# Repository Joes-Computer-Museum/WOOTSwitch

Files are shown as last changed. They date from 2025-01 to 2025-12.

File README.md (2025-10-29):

WOOTSwitch
==========

WOOTSwitch is a hardware fork of hootswitch by saybur.
WOOTSwitch is a prototype [ADB](https://en.wikipedia.org/wiki/Apple_Desktop_Bus)
multiplexer that allows peripherals (inluding keyboards and mice) to be shared
across up to four retro computers.

This project has two parts: an hardware design and the firmware,
located in their respective folders in this repo.

The hardware design uses Raspberry Pi Pico design files found here:
https://github.com/HeadBoffin/RP_Silicon_KiCad

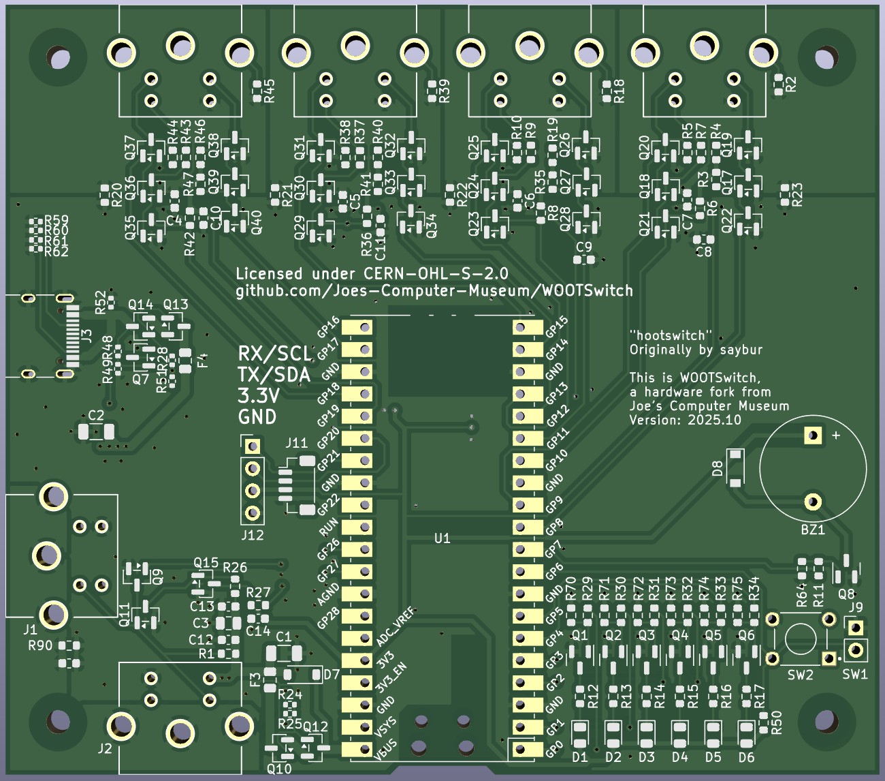
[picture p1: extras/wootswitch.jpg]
WOOTSwitch


Status
------

Basic ADB keyboards and mice are supported. Switching between computers works
via the button on the front or <kbd>Control</kbd> / <kbd>Option</kbd> /
<kbd>⌘</kbd> / <kbd>Shift</kbd> in sequence, followed by <kbd>1</kbd> -
<kbd>4</kbd> to choose a port.

The firmware is still under active development and many bugs remain. Known
issues include:

- Mouse input can be a bit "floaty" especially during extreme movements.
- No other ADB devices besides keyboards/mice are supported yet.
- No features based on the Pico W wireless chip have not been implemented.

This section will continue to be updated as progress is (hopefully) made.

Building
--------

You will need the Pico SDK and associated tooling. There is a setup script
[here](https://raw.githubusercontent.com/raspberrypi/pico-setup/master/pico_setup.sh)
that assumes you're using a Raspberry Pi as your development environment if you
want to try that; I personally use Debian _bookworm_ on a regular x86 system
instead, set up as follows.

Dependencies and associated tools:

```
sudo apt install git cmake gcc-arm-none-eabi gcc gdb-multiarch automake \
    autoconf build-essential texinfo libtool libftdi-dev libusb-1.0-0-dev \
    openocd
```

Clone the [Pico SDK](https://github.com/raspberrypi/pico-sdk). Execute
`git submodule update --init` in that project to get sub-libraries added. Set
`PICO_SDK_PATH` to point at where the SDK lives via `~/.bashrc` or equivalent;
something like `export PICO_SDK_PATH=/home/saybur/src/pico-sdk` would be
suitable after being adjusted for your environment.

Also clone or download [FreeRTOS](https://github.com/FreeRTOS). The LTS release
is likely fine. Set `FREERTOS_KERNEL_PATH` to the folder where
`FreeRTOS-Kernel` is located via the above method.

Once you have everything set up, build as follows from the root of the repo.

```
mkdir -p build
cd build
cmake ../firmware
make
```

Among other files, this will produce `hootswitch.uf2`. Make sure your power
selection is correct, then hold down the BOOTSEL button while you plug in
to your computer via USB. Copy the `.uf2` onto the new mass storage device.
Reboot.

Licenses
--------

Except where otherwise noted, all software is available under the GNU GPL v3.
The example hardware is available under the CERN Open Hardware Licence
strongly-reciprocal variant, version 2. Refer to the licenses for specific
terms.

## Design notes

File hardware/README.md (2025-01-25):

Hootswitch Hardware
===================

_IMPORTANT NOTE_: the DC power jack does not work on any board revision due to
a design error. If you make PCBs based on this design only USB power will
function. You can work around this problem by bodging a wire from the negative
terminal of the DC jack to a nearby ground connection but that isn't great for
such an important connection.

This folder has the hardware design being used to develop the firmware. Known
issues with it include:

- Some features are untested, including alternate power modes.
- C1 in the BOM is wrong. Since I am not using the power input at the moment I
  left it unpopulated.
- There is no keepout for the wireless chip, which may negatively impact
  reception.
- Annular rings on the mini-DIN connectors are on the small side.
- Green LEDs are too bright. Adjusted in 2024a with PWM. Future revision needs
  stronger resistors.
- Mounting holes are too small for the standard screws. These are also a tad
  too close to the connectors.
- A connection should be made between host power-on and a free GPIO. This can
  be worked around in software with keyboards.
- It might have been wiser to put bus input pins to GPIOs with PWM B inputs.
  This will probably not be changed, PIO handles everything fine.

Anticipate that a future revision will be made with corrections.
[CHANGES.txt](CHANGES.txt) will have any applicable history.

This project is made available under the CERN Open Hardware Licence
strongly-reciprocal variant version 2, available at [LICENSE](LICENSE).

This is distributed WITHOUT ANY EXPRESS OR IMPLIED WARRANTY, INCLUDING OF
MERCHANTABILITY, SATISFACTORY QUALITY AND FITNESS FOR A PARTICULAR PURPOSE.
Please see the CERN-OHL-S v2 for applicable conditions.

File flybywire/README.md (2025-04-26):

Fly-By-Wire
===========

The web portion of the serial link control system used by Hootswitch. Visit
<https://saybur.github.io/hootswitch/flybywire/> to access.

To set configuration information, visit
<https://saybur.github.io/hootswitch/flybywire/config.html> and refer to the
wiki for additional information.

External Dependencies
---------------------

- `simple_keyboard.js` and `simple-keyboard.css` are from the
[Simple Keyboard](https://github.com/hodgef/simple-keyboard) project.
- `keyboard-capture.js` and `keyboard-capture.css` are from the
[IP-KVM-InterFace](https://github.com/SterlingButters/ip-kvm-interface)
project. Refer to those files for license information.
- `crc32.js` is in the public domain and is from
[https://simplycalc.com/crc32-source.php](https://simplycalc.com/)

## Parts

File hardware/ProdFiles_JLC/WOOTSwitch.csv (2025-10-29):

Designation | Designator | Footprint | LCSC Part Number
1M | R52,R51 | R_0402_1005Metric | C26083
10k | R49,R28,R25,R62,R61,R60,R59 | R_0402_1005Metric | C25744
100 | R48,R24 | R_0402_1005Metric | C25076
AO3401A | Q14,Q13,Q12,Q10 | SOT-23 | C15127
47uF | C1,C2 | C_1206_3216Metric | C96123
500mA | F4,F3 | Fuse_0805_2012Metric | C883111
B5819W | D7,D8 | D_SOD-123 | C8598
AO3400A | Q7 | SOT-23 | C20917
USB_C_Receptacle | J3 | USB_C_Receptacle_HRO_TYPE-C-31-M-12 | C165948
4.7k | R5,R9,R44,R10,R43,R37,R7,R38,R50 | R_0603_1608Metric | C23162
33 | R39,R90,R2,R18,R45 | R_0603_1608Metric | C23140
10k | R20,R46,R21,R35,R41,R47,R40,R4,R3,R22,R19,R26,R23,R72,R73,R71,R64,R75,R70,R74 | R_0603_1608Metric | C25804
2N7002 | Q22,Q28,Q20,Q23,Q27,Q29,Q36,Q9,Q15,Q31,Q21,Q35,Q19,Q34,Q33,Q30,Q38,Q24,Q11,Q39,Q40,Q32,Q26,Q18,Q25,Q17,Q37 | SOT-23 | C8545
RLED | D1 | LED_0805_2012Metric | C84256
LED | D3,D5,D4,D6 | LED_0805_2012Metric | C2297
YLED | D2 | LED_0805_2012Metric | C2296
100nF | C13,C8,C12,C14,C9,C11,C10 | C_0603_1608Metric | C14663
10n | C5,C4,C7,C6 | C_0603_1608Metric | C57112
1k | R6,R42,R27,R8,R36,R12,R15,R13,R11,R16,R14,R17 | R_0603_1608Metric | C21190
MMBT3904 | Q8,Q3,Q1,Q4,Q2,Q6,Q5 | SOT-23 | C20526
2K2 | R31,R29,R32,R30,R33,R34 | R_0603_1608Metric | C4190
1825910-6 | SW2 | SW_1825910-6-4 | C428628
470 | R1 | R_0603_1608Metric | C23179
10uF | C3 | C_0805_2012Metric | C15850

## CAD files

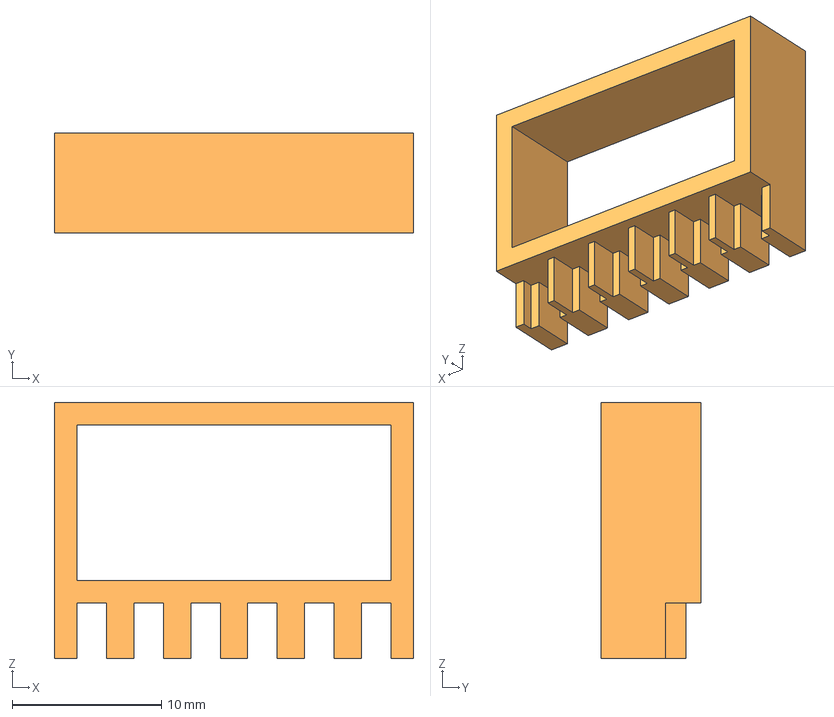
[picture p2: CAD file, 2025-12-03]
hardware/enclosure/WOOTswitch Enclosure - Light Pipe Comb.step
24.0 x 6.68 x 17.1 mm

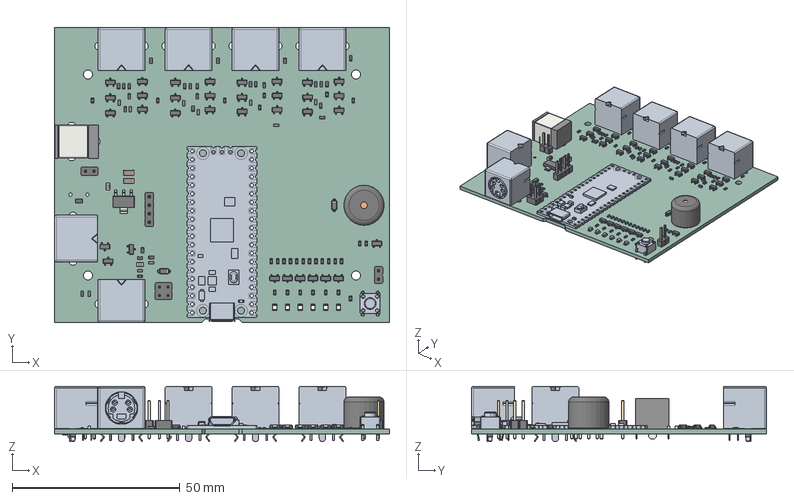
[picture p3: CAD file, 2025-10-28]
hardware/WOOTSwitch.step
100.0 x 88.0 x 16.6 mm
R_0603_1608Metric x 53
SOT-23 x 34
LED_0805_2012Metric x 6
C_0603_1608Metric x 11
L_0603_1608Metric
Fuse_0805_2012Metric
c-5749181-1-a-3d x 6
PinHeader_1x02_P2.54mm_Vertical x 2
c-1825910-6-c-3d
BarrelJack_CUI_PJ-063AH_Horizontal
WOOTSwitch 1.57.1
SOT-223
Buzzer_12x9.5RM7.6
C_1206_3216Metric x 2
PinHeader_1x04_P2.54mm_Vertical
D_SOD-123 x 2
C_0805_2012Metric x 2
PinHeader_2x02_P2.54mm_Vertical
WOOTSwitch_PCB

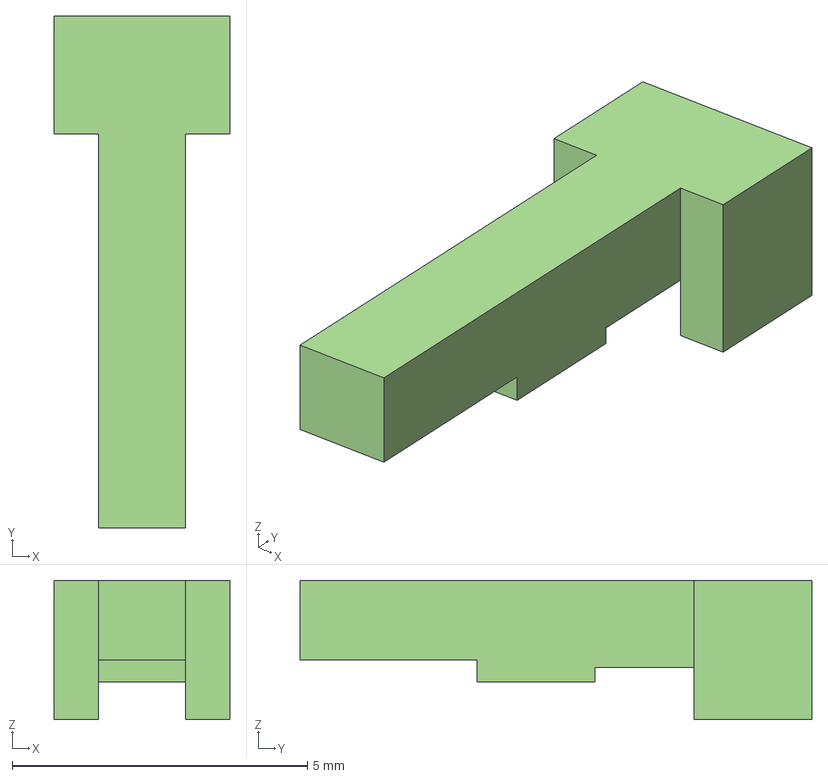
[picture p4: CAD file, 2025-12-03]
hardware/enclosure/WOOTswitch Enclosure - Light Pipe.step
2.97 x 8.68 x 2.36 mm

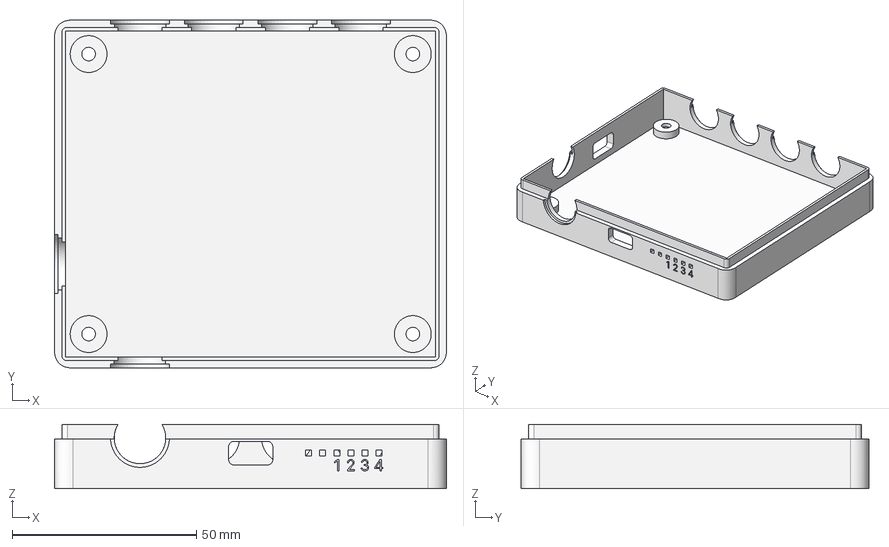
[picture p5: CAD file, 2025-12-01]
hardware/enclosure/WOOTswitch Enclosure - Bottom.step
106.4 x 94.4 x 17.4 mm

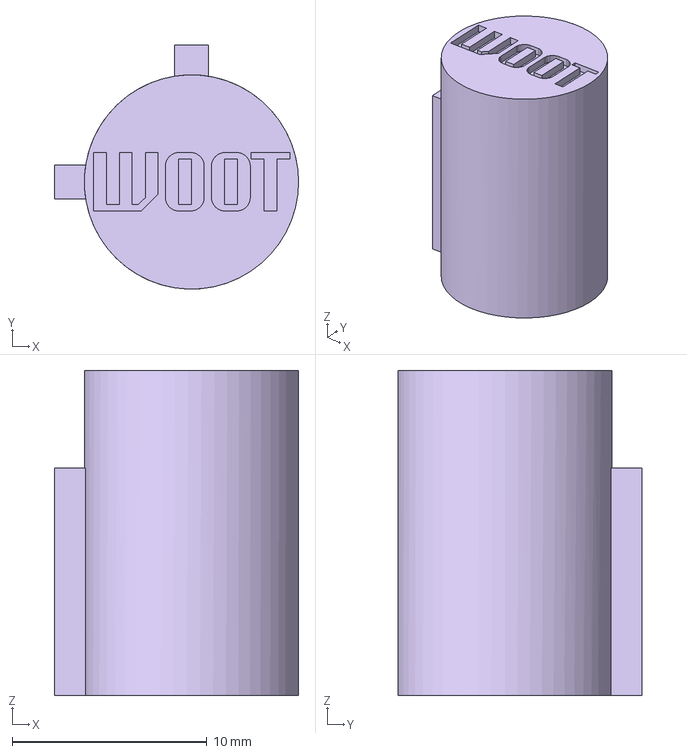
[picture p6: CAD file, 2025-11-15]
hardware/enclosure/WOOTswitch Enclosure - Button.step
12.5 x 12.5 x 16.7 mm

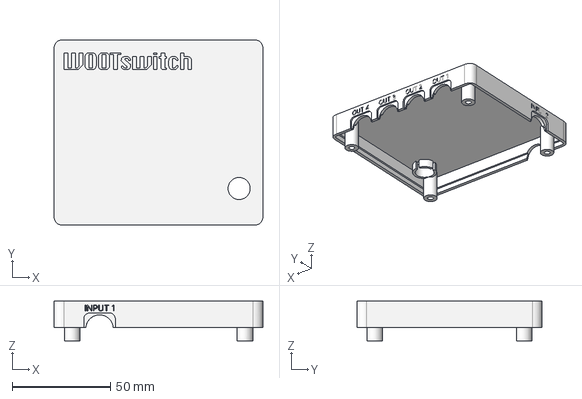
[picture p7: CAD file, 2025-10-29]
hardware/enclosure/WOOTswitch Enclosure - Top.step
106.4 x 94.4 x 20.3 mm

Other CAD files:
hardware/enclosure/WOOTswitch Enclosure - Bottom.stl
hardware/enclosure/WOOTswitch Enclosure - Button.stl
hardware/enclosure/WOOTswitch Enclosure - Light Pipe Comb.stl
hardware/enclosure/WOOTswitch Enclosure - Light Pipe.stl
hardware/enclosure/WOOTswitch Enclosure - Top.stl

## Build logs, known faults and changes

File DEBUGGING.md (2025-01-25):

Debugging
=========

These are notes for a potential way to debug the device during development.
This is how I (@saybur) personally like working on it in a Linux desktop
environment.

Logging
-------

Hootswitch will log some aspects of device detection, host startup, and similar
lifecycle events to the USB CDC device. Connect at 115200 baud, 8-N-1.

Hardware
--------

To capture ADB signals I use an inexpensive logic analyzer compatible with the
`fx2lafw` firmware from the
[sigrok](https://sigrok.org/wiki/Main_Page) project. To sample the device-side
the passthrough ADB connector works great. For one of the hosts you can either
use the second ADB port on a computer that has one (IIci and the like) or a
hacked-together ADB splitter of some kind.

[PulseView](https://sigrok.org/wiki/PulseView) works for reviewing captures. It
works even better with an ADB decoder like
[decoder-adb](https://github.com/tmk/decoder-adb). On my system that had to be
installed in ` ~/.local/share/libsigrokdecode/decoders` in an `adb` subfolder.

Software
--------

You will want to invoke `cmake` with `-DCMAKE_BUILD_TYPE=Debug`.

[The official debugger](https://www.raspberrypi.com/documentation/microcontrollers/debug-probe.html)
is dirt cheap and works reasonably well if you plan to develop on the firmware.
It can be used as follows to upload without needing to fuss with the BOOTSEL
button. Be in the `dialout` group to avoid needing `sudo` all over the place.
OpenOCD can be started as follows.

```
openocd -c "set USE_CORE 0" -f interface/cmsis-dap.cfg -f target/rp2040.cfg \
    -c "adapter speed 5000" -c "rp2040.core0 configure -rtos FreeRTOS"
```

See <https://github.com/raspberrypi/pico-sdk/issues/1622> for a discussion
about `USE_CORE 0` above. The above is fine for now with the current state of
development, which runs only on a single core anyway.

In another terminal, run `gdb-multiarch hootswitch.elf`. Connect to the device
with `target remote localhost:3333` (or automate this step via `~/.gdbinit`).
See [the documentation](https://openocd.org/doc/html/General-Commands.html) for
specifics; the following commands are likely useful (with the caveat that I am
_most definitely_ not an authority on `gdb`):

* `load` will update programming with the current ELF.
* `monitor reset init` will restart and halt for instructions.
* `print X` prints information about something, including variables.
* `br X` adds a breakpoint at X, `del` removes one or more.
* `continue` will proceed, stopping at breakpoints; Ctrl-C halts.
* `finish` completes a function.
* `bt` prints a backtrace, `bt f` prints a backtrace with symbols.
* `up` and `down` moves around the frames of a call.
* `i r` prints registers.
* `p X` prints variable X.
* `p/x *0x0` prints in hex from the address, useful for peripheral registers.
* `i threads` prints information relevant to FreeRTOS thread execution.

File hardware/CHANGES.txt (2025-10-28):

DESIGN CHANGES

Refer to section 3.3.b of the license for information that must be included in
this document.

- 23 July 2024, rev 2024a: first design
- September 2025, rev 2025.09: Changed to mosfets for isolation
- October 2025, rev 2025.10: Changed pushbutton, rebranded as WOOTSwitch

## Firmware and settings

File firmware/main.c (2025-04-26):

/*
 * Copyright (C) 2024 saybur
 *
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
 * You should have received a copy of the GNU General Public License
 * along with this program.  If not, see <https://www.gnu.org/licenses/>.
 */

#include <stdio.h>
#include "pico/stdlib.h"
#include "pico/cyw43_arch.h"
#include "hardware/gpio.h"

#include "FreeRTOS.h"
#include "task.h"

#include "button.h"
#include "buzzer.h"
#include "computer.h"
#include "config.h"
#include "control.h"
#include "debug.h"
#include "driver.h"
#include "host.h"
#include "hardware.h"
#include "led.h"
#include "usb.h"

#define PROGRAM_NAME       "hootswitch-v20250426"

#define DEFAULT_STACK      configMINIMAL_STACK_SIZE
#define DEFAULT_PRIORITY   (tskIDLE_PRIORITY + 1U)
#define DISPATCH_PRIORITY  (tskIDLE_PRIORITY + 2U)

static void init_hardware(void)
{
	led_init();

	buzzer_init();
	host_init();
	computer_init();

	// setup input switch
	gpio_init(SWITCH_PIN);
	gpio_pull_up(SWITCH_PIN);
}

static void init_config(void)
{
	config_setup();

	// read core configuration information, and on failure leave at defaults
	uint8_t core;
	if (config_read(CONFIG_OFFSET_BASE, &core, 1)) {
		return;
	}

	if (! (core & 1)) {
		buzzer_enable(false);
	}
}

static void init_task(__unused void *parameters)
{
	// wait for USB enumeration, and for ADB devices to power up themselves up
	busy_wait_ms(1600);

	// handle alternate startup conditions
	switch (control_check_reset()) {
		case RESET_TYPE_DEBUG:
			// wait for a USB UART to connect
			bool led = false;
			while (! stdio_usb_connected()) {
				vTaskDelay(100);
				cyw43_arch_gpio_put(CYW43_WL_GPIO_LED_PIN, led);
				led = !led;
			}
			cyw43_arch_gpio_put(CYW43_WL_GPIO_LED_PIN, 1);
			break;
	}

	dbg(PROGRAM_NAME);
	init_config();
	led_activity(true);
	handler_init();

	host_err herr;
	if (herr = host_reset_bus()) {
		dbg_err("host bus reset err %d", herr);
		led_error(true);
	}
	busy_wait_ms(1);
	if (herr = host_reset_devices()) {
		dbg_err("host device reset err %d", herr);
		led_error(true);
	} else {
		dbg("host reset ok!");
	}

	driver_init();
	computer_start();
	computer_switch(1, true);
	control_start();

	xTaskCreate(computer_task, "computer", DEFAULT_STACK,
			NULL, DISPATCH_PRIORITY, NULL);
	xTaskCreate(host_task, "host", DEFAULT_STACK,
			NULL, DISPATCH_PRIORITY, NULL);
	xTaskCreate(button_task, "button", DEFAULT_STACK,
			NULL, DEFAULT_PRIORITY, NULL);
	xTaskCreate(control_task, "control", configMINIMAL_STACK_SIZE,
			NULL, tskIDLE_PRIORITY, NULL);

	vTaskDelete(NULL);
}

int main(void)
{
	usb_dev_init();
	stdio_init_all();
	if (cyw43_arch_init()) {
		panic("unable to init cyw43, is this a Pico W?");
	}
	cyw43_arch_gpio_put(CYW43_WL_GPIO_LED_PIN, 1);

	init_hardware();

	xTaskCreate(init_task, "init", DEFAULT_STACK,
			NULL, DEFAULT_PRIORITY, NULL);
	xTaskCreate(usb_dev_task, "usb_dev", DEFAULT_STACK * 3,
			NULL, configMAX_PRIORITIES - 1, NULL);

	while (true) {
		vTaskStartScheduler();
	}
}

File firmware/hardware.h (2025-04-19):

/*
 * Copyright (C) 2024 saybur
 *
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
 * You should have received a copy of the GNU General Public License
 * along with this program.  If not, see <https://www.gnu.org/licenses/>.
 */

#ifndef __HARDWARE_H__
#define __HARDWARE_H__

/*
 * ----------------------------------------------------------------------------
 *     PIN DEFINITIONS
 *   Change these to match your hardware.
 * ----------------------------------------------------------------------------
 *
 * The RP2040 has fewer "gotchas" than other MCUs but there still are some
 * limitations to be aware of if you're trying a new board spin:
 *
 * - LEDs should not be on PWMs shared with other periphals that use the PWM
 *   system, such as the buzzer, or you will need to adjust the LED driving
 *   code.
 * - Generally try to have the _DO lines on PWM_CHB (odd GPIOs), they are the
 *   only ones with duty cycle / frequency measuring. This is not currently
 *   implemented, PIO handles all that stuff, but it might be useful in the
 *   future.
 */

#define LED_ERR_PIN         0
#define LED_ACT_PIN         1
#define LED_C1_PIN          2
#define LED_C2_PIN          3
#define LED_C3_PIN          4
#define LED_C4_PIN          5
#define SWITCH_PIN          6
#define BUZZER_PIN          7
#define A_DO_PIN            26
#define A_DI_PIN            27
#define C1_DO_PIN           18
#define C1_DI_PIN           19
#define C1_PSW_PIN          17
#define C2_DO_PIN           15
#define C2_DI_PIN           16
#define C2_PSW_PIN          14
#define C3_DO_PIN           12
#define C3_DI_PIN           13
#define C3_PSW_PIN          11
#define C4_DO_PIN           9
#define C4_DI_PIN           10
#define C4_PSW_PIN          8

/*
 * ----------------------------------------------------------------------------
 *     RESOURCE DEFINITIONS / ALIASES
 *   Use care changing anything past this line!
 * ----------------------------------------------------------------------------
 */

// "computer" refers to the emulated device ports on the back
#define COMPUTER_PIO        pio0
#define COMPUTER_PIO_IRQ0   PIO0_IRQ_0
#define COMPUTER_COUNT      4

// device DMA units, used to handle initial signal detection and Listen data
#define COMPUTER_DMA_IRQ    DMA_IRQ_1
#define COMPUTER_DMA_IDX    1
#define COMPUTER_DMA_INTS   dma_hw->ints1
#define COMPUTER_0_DMA      6
#define COMPUTER_1_DMA      7
#define COMPUTER_2_DMA      8
#define COMPUTER_3_DMA      9

// additional DMA channel used for handling configuration data
#define CONFIG_DMA_CHAN     5

// "host" refers to the connection with the native peripherals on the front
#define HOST_PIO            pio1
#define HOST_PIO_IRQ0       PIO1_IRQ_0

#define BUZZER_TIMER        2
#define BUZZER_TIMER_IRQ    TIMER_IRQ_2
#define COMPUTER_TIMER      1
#define COMPUTER_TIMER_IRQ  TIMER_IRQ_1
#define HOST_TIMER          0
#define HOST_TIMER_IRQ      TIMER_IRQ_0

#define A_DO_PIN_bm         (1U << A_DO_PIN)
#define C1_DO_PIN_bm        (1U << C1_DO_PIN)
#define C2_DO_PIN_bm        (1U << C2_DO_PIN)
#define C3_DO_PIN_bm        (1U << C3_DO_PIN)
#define C4_DO_PIN_bm        (1U << C4_DO_PIN)

#define A_DO_PIN_bm         (1U << A_DO_PIN)
#define C1_DO_PIN_bm        (1U << C1_DO_PIN)
#define C2_DO_PIN_bm        (1U << C2_DO_PIN)
#define C3_DO_PIN_bm        (1U << C3_DO_PIN)
#define C4_DO_PIN_bm        (1U << C4_DO_PIN)

#endif /* __HARDWARE_H__ */

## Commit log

2025-01-20 Adding warning in hardware for DC power jack not working.
2025-01-25 Actually adding warning about the power jack problem (sigh)
2025-01-25 Moving to PID from pid.codes
2025-01-25 Slowing down rate of polling for device-side.
    This seems to result in a slightly smoother mouse experience.
2025-02-15 Disregard device handler IDs for keyboards/mice.
    Will now attempt to put all keyboards into extended mode if able.
2025-03-28 Oops, don't use the global here. Was causing errors on non-error commands.
    [host.c]
2025-03-28 Stretch reset to account for devices that may have bad timing.
    [host.c]
2025-03-28 Allow device handlers to choose SRQ flag status.
2025-03-28 Extend reset pulse from 3 to 4ms to ensure it is seen by devices.
    Also matches observed IIci reset pulse.
    [host.c]
2025-03-29 Change reset pulse to just drive line low, to match observed ROM action.
    [host.c]
2025-03-31 Redo address algorithm to round-robin devices and improve error handling.
    This more closely resembles what the IIci does on boot. The retries on messages should hopefully handle conditions when a device is being sluggish in responding to the host as well.
    [host.c]
2025-04-01 Timing tweaks to get Gravis joysticks working.
    This was *maddening* to figure out. These changes made both a Gravis Blackhawk and Thunderbird go from not working to working. It appears they are quite fussy about ADB timing, much more than the +/-3% AN591 suggests.
    [host.c]
2025-04-16 Allow buzzer to be disabled via compile flag.
    Useful during development if the device is crashing while buzzing. Ask me how I know :(
    [buzzer.c]
2025-04-16 Allow drivers to insert data during reset phase.
    [computer.c]
2025-04-16 Fix instances where SRQ could be set but not unset.
    I think this was causing some intermittent SRQ loops, where SRQ was being issued but never satisfied.
    [computer.c]
2025-04-16 Support returning 0xFF from handler functions to disable Talk 3 responding.
    This is needed for Kensington devices.
2025-04-17 Lift serial dispatcher out of driver, add reset-over-serial option.
    [computer.c, main.c]
2025-04-17 Add support for fly-by-wire to execute a debugging restart.
    When issued the device will restart and then halt, fast-flashing the Pico LED until a USB serial device connects. Goal is to let a user see the startup messages in real time without needing to cache anything in memory. This may not be a bright idea but it seems to work OK for the moment.
    This still needs to be documented properly.
    [main.c]
2025-04-17 Light the red LED when something goes wrong during host enumeration.
    [main.c]
2025-04-19 Adds a simple (optional) device configuration system.
    This works as a block of binary configuration data with a web-based programmer interface. Data is stored in a 4K page in the far part of the flash chip.
    So far only configuration option is disabling the buzzer. No serialization support for the interface.
    [buzzer.c]
2025-04-20 Maintain separate host iterator list to avoid reordering device IDs.
    Also makes the SRQ iteration order more like a real system.
    [host.c]
2025-04-22 Untested support for Kensington device emulation flags.
2025-04-26 Track only 32 bits of time for phase changing, plus more debug support.
2025-04-26 Missing variables from earlier commit.
    [computer.c]
2025-10-20 Hardware Fork: Use Mosfets For Isolation
    [hootswitch-B_Cu.gbl, hootswitch-B_Mask.gbs, hootswitch-B_Paste.gbp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]
2025-10-28 Rebrand as WOOTSwitch
    [WOOTSwitch-computers.kicad_sch, WOOTSwitch.kicad_pcb, WOOTSwitch.kicad_sch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]
2025-10-28 Production files for JLC - not quite complete
    [WOOTSwitch-B_Cu.gbl, WOOTSwitch-B_Mask.gbs, WOOTSwitch-B_Paste.gbp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]
2025-10-28 added 3d models for ports, switch, and pico, and added step file for board with components shown
    [Pico-R3.step, WOOTSwitch.kicad_pcb, WOOTSwitch.step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]
2025-10-28 Add sheet for power net
    [WOOTSwitch.kicad_sch]
2025-10-29 Moved mounting holes
    [WOOTSwitch-B_Cu.gbl, WOOTSwitch-B_Mask.gbs, WOOTSwitch-B_Paste.gbp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]
2025-10-29 added usb-c 3d model and embedded 3d models.
    [Pico-R3.step, WOOTSwitch.kicad_pcb, c-1825910-6-c-3d.stp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]
2025-10-29 updated step file for board
    [WOOTSwitch.step]
2025-10-29 switched to a better usb-c 3d model
    [WOOTSwitch.kicad_pcb]
2025-10-29 added models for the enclosure
    [WOOTswitch Enclosure - Bottom.step, WOOTswitch Enclosure - Bottom.stl, WOOTswitch Enclosure - Button.step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]
2025-10-29 changed logos on enclosure
    [WOOTswitch Enclosure - Bottom.step, WOOTswitch Enclosure - Bottom.stl, WOOTswitch Enclosure - Button.step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]
2025-11-15 made lettering on button deeper
    [WOOTswitch Enclosure - Button.step, WOOTswitch Enclosure - Button.stl]
2025-11-15 changed lettering on button again
    [WOOTswitch Enclosure - Button.step, WOOTswitch Enclosure - Button.stl]
2025-12-01 added holes and light pipes for the LEDs
    [WOOTswitch Enclosure - Bottom.step, WOOTswitch Enclosure - Bottom.stl, WOOTswitch Enclosure - Light Pipe.step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]
2025-12-03 revised the light pipes and added a comb to prevent light bleed
    [WOOTswitch Enclosure - Light Pipe Comb.step, WOOTswitch Enclosure - Light Pipe Comb.stl, WOOTswitch Enclosure - Light Pipe.step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]

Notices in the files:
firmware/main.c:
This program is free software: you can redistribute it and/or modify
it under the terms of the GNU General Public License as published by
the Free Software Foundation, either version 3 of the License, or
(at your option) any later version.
